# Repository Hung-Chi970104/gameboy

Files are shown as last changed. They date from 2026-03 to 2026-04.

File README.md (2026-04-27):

# Pico Gameboy
I came across with this DIY Gameboy video made of Raspberry Pi Pico and inspired me to build my own version. The fact that RP2040 has dual-core ARM Cortex-M0+ processor makes it capable of running some light emulators. So I’ll build a little handheld game console using RP2040 that can run gameboy!
### Kirby's Dream Land 2 (My favorite)
https://github.com/user-attachments/assets/909a369a-9677-4903-9628-0e65bedbe7ed

### Tetris (my unemployed friend LMAO)
https://github.com/user-attachments/assets/1b85eab4-04bd-4f8f-a2d0-78ee750a4273

# Features
- Full-on Gameboy experience: Actually runs the classics smoothly without freaking out.
- Insanely portable: Squeezed everything into a super compact custom PCB so you can just chuck it in your pocket.
- 100% Custom Hardware: Fully designed, routed, and reflowed by yours truly (my eyes are still bleeding from staring at KiCad traces bruh).

# Components
- RP2040
- 12MHz Crystal (ABM8-272-T3)
- 8MB Flash Storage (W25Q64JVXGIQ)
- Buck-Boost Switching Regulator (RT6150B)
- USB-C (TYPE-C-31-M-12)

# PCB Designs
- 2 layers
- Single-sided component placement
- 2.6mm board thickness
- HASL (with lead) surface finish
- 1oz outer copper weight

## PCB Schematic
schemtatic

## PCB Layouts
pcb_front
pcb_back
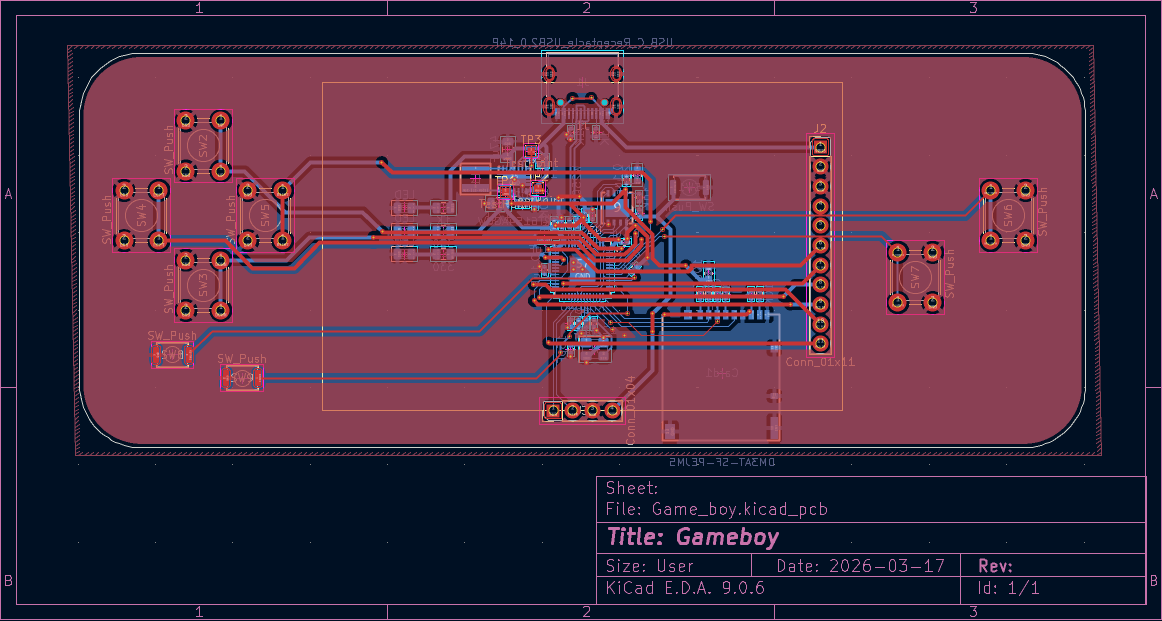
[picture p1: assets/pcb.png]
pcb_design


## 3D Model
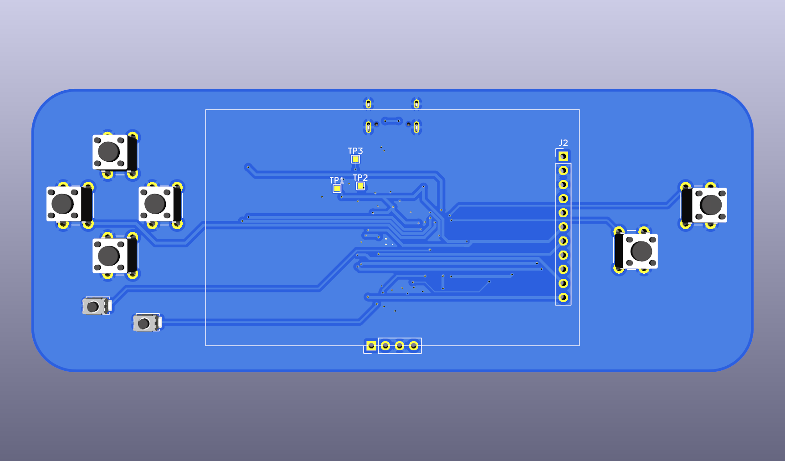
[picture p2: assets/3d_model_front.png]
3d_model_front

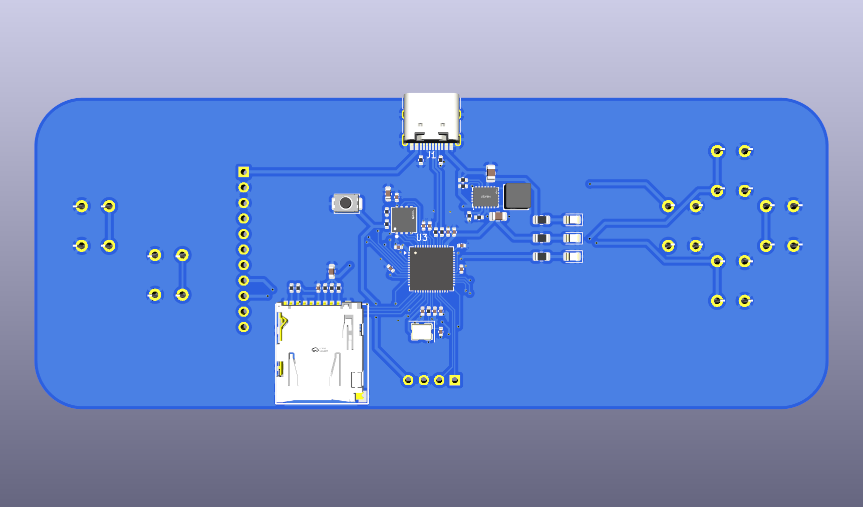
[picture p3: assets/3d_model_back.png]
3d_model_back


# How to order
- Download the zip file
- Upload the zip file to JLCPCB
- Select PCBA and continue
- Upload BOM.csv and position.csv
- Select the parts and submit payment

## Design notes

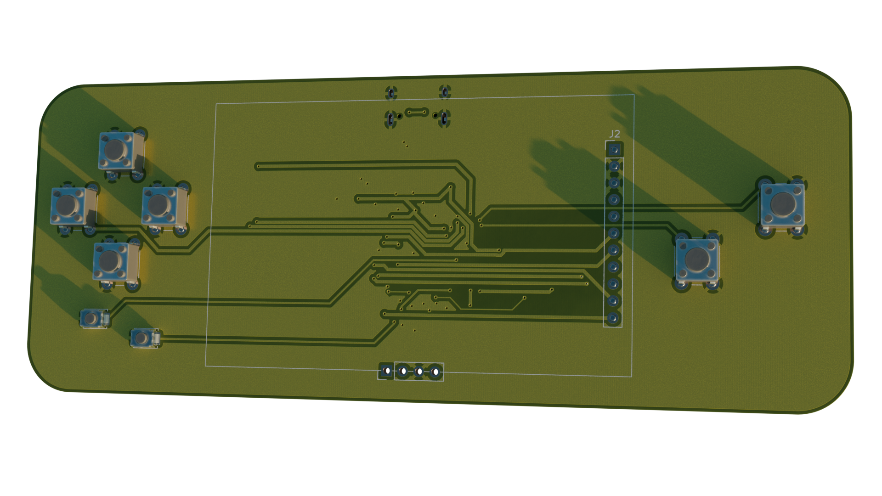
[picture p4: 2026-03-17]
assets/gameboy_front.png

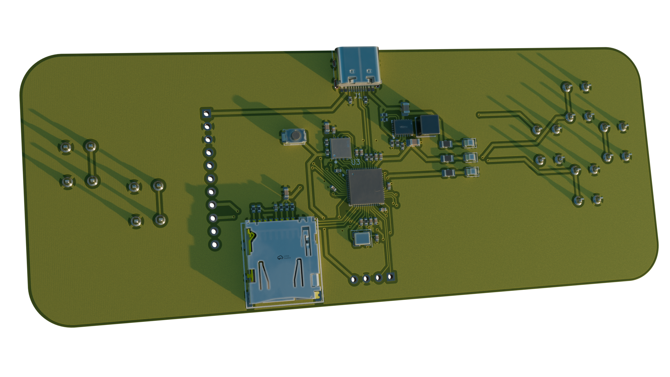
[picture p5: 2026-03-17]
assets/gameboy.png

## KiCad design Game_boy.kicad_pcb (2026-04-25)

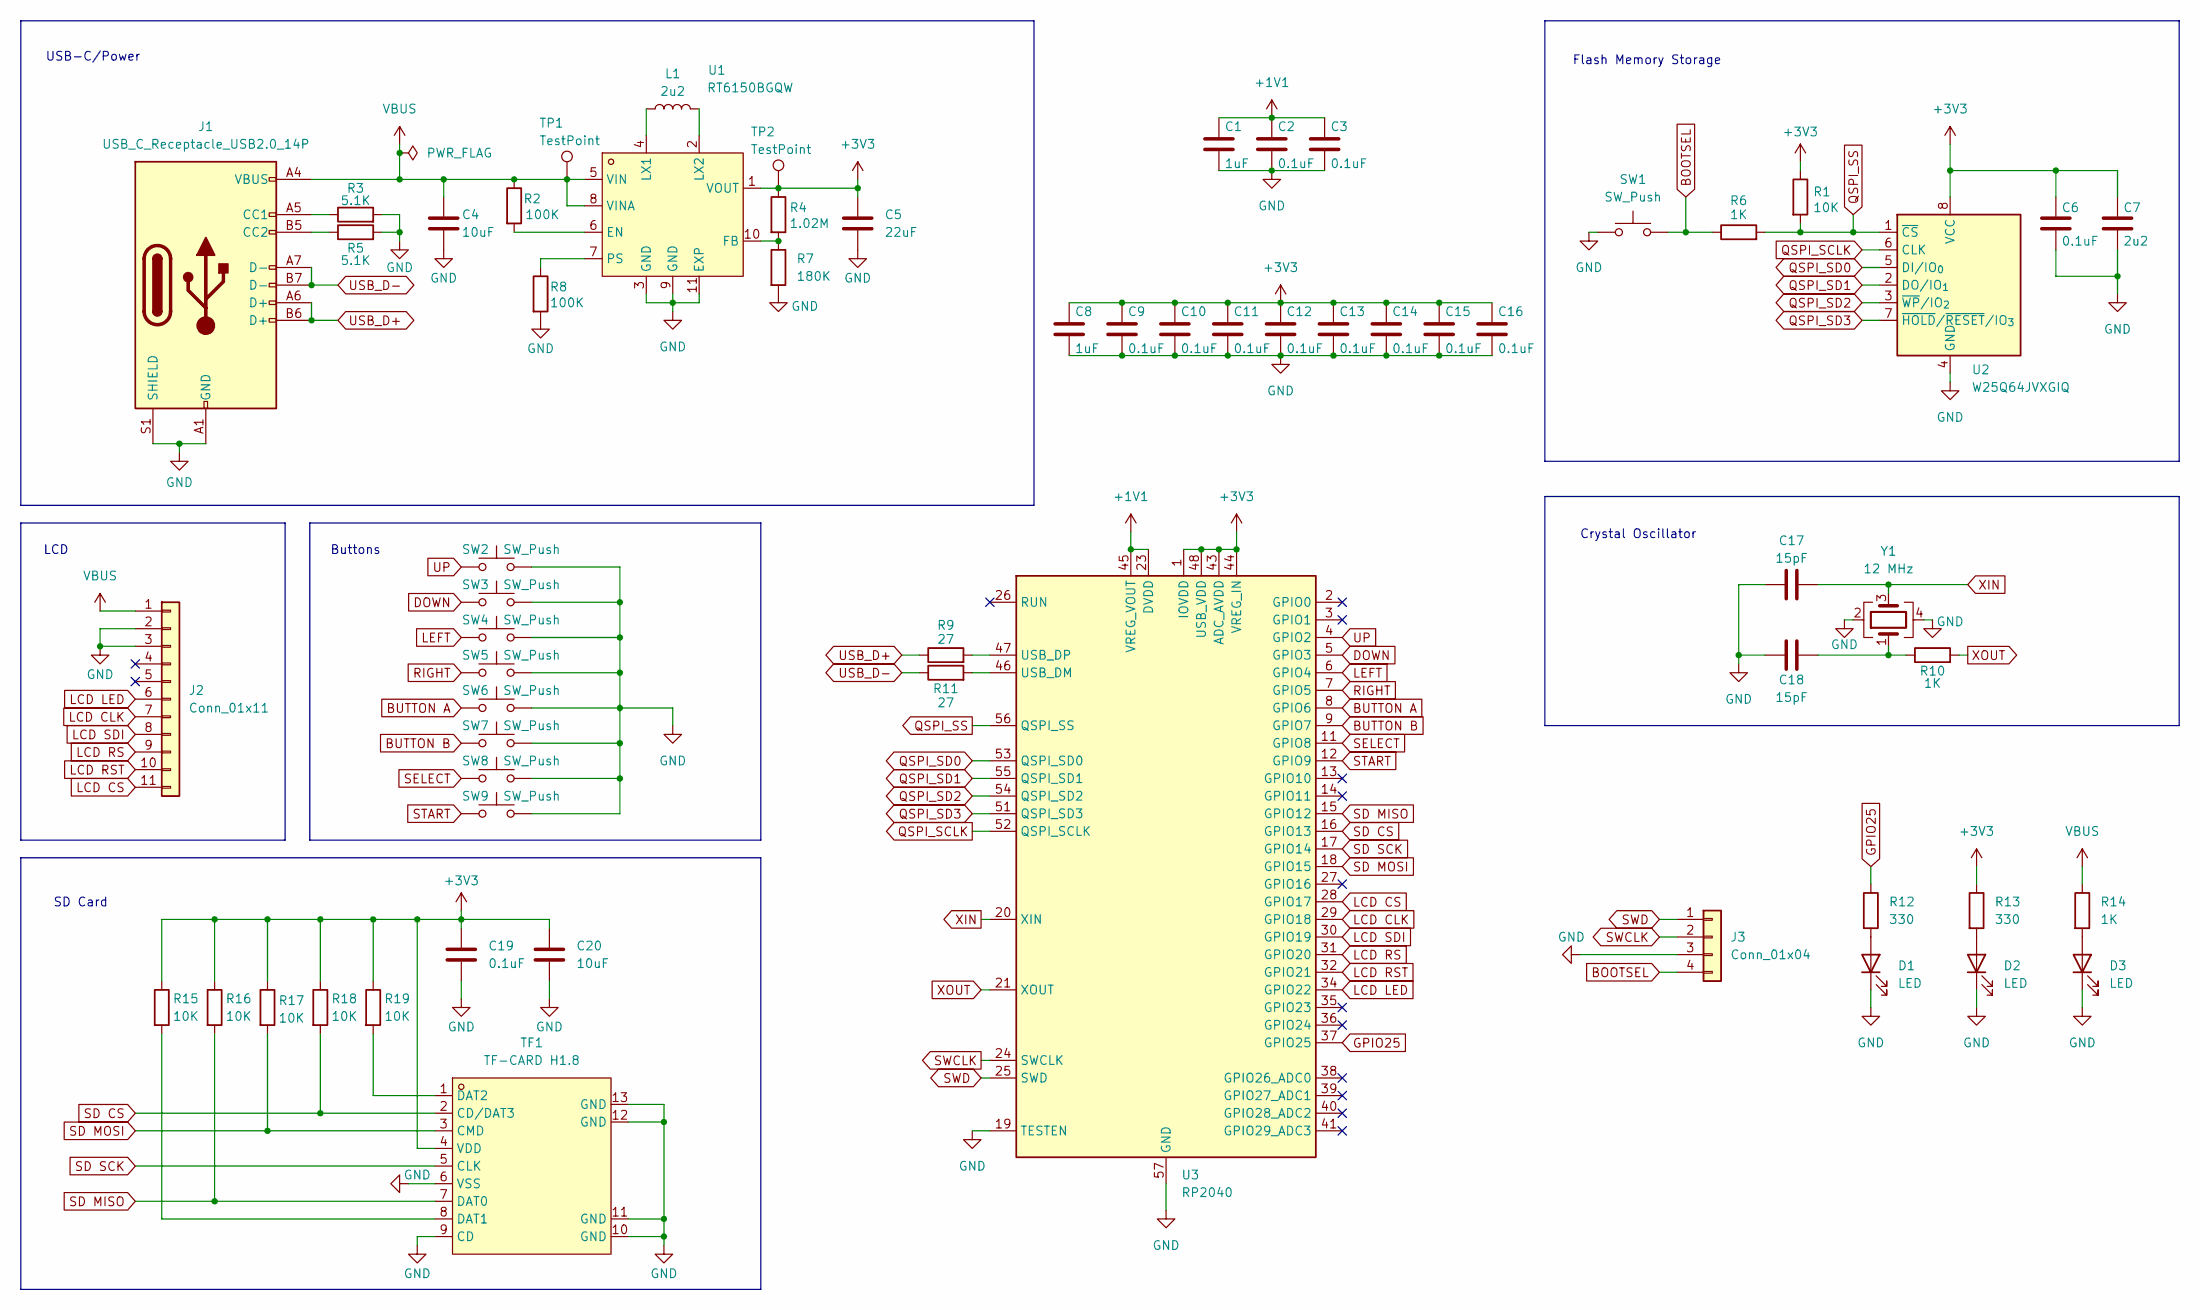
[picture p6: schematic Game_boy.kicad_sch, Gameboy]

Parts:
C1, C8: 1uF; C_0402_1005Metric
C2, C3, C6, C9, C10, C11, C12, C13, C14, C15, C16, C19: 0.1uF; C_0402_1005Metric
C4: 10uF; C_1206_3216Metric
C5: 22uF; C_1206_3216Metric
C7: 2u2; C_0603_1608Metric
C17, C18: 15pF; C_0402_1005Metric
C20: 10uF; C_0603_1608Metric
D1, D2, D3: LED; LED_0805_2012Metric
J1: USB_C_Receptacle_USB2.0_14P; USB_C_Receptacle_HRO_TYPE-C-31-M-12
J2: Conn_01x11; PinHeader_1x11_P2.54mm_Vertical
J3: Conn_01x04; PinHeader_1x04_P2.54mm_Vertical
L1: 2u2; IND-SMD_L4.0-W4.0_XAL4030-332MEC
R1, R15, R16, R17, R18, R19: 10K; R_0402_1005Metric
R2, R8: 100K; R_0402_1005Metric
R3, R5: 5.1K; R_0402_1005Metric
R4: 1.02M; R_0402_1005Metric
R6, R10: 1K; R_0402_1005Metric
R7: 180K; R_0402_1005Metric
R9, R11: 27; R_0402_1005Metric
R12, R13: 330; R_0805_2012Metric
R14: 1K; R_0805_2012Metric
SW1, SW8, SW9: SW_Push; SW_Push_SPST_NO_Alps_SKRK
SW2, SW3, SW4, SW5, SW6, SW7: SW_Push; SW_PUSH_6mm
TF1: TF-CARD H1.8; TF-SMD_TF-CARD-H1.8; LCSC Part C7529389
TP1, TP2: TestPoint; TestPoint_Pad_1.0x1.0mm
U1: RT6150BGQW; WSON-10_L2.5-W2.5-P0.50-BL-EP; LCSC Part C147972
U2: W25Q64JVXGIQ; XSON-8_L4.0-W4.0-P0.80-TL-EP
U3: RP2040; QFN-56-1EP_7x7mm_P0.4mm_EP3.2x3.2mm
Y1: 12 MHz; Crystal_SMD_3225-4Pin_3.2x2.5mm

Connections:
+1V1: C1.1, C2.1, C3.1, U3.23 (DVDD), U3.45 (VREG_VOUT), U3.50 (DVDD)
+3V3: C5.1, C6.1, C7.1, C8.1, C9.1, C10.1, C11.1, C12.1, C13.1, C14.1, C15.1, C16.1, C19.1, C20.1, R1.1, R4.1, R13.1, R15.1, R16.1, R17.1, R18.1, R19.1, TF1.4 (VDD), TP2.1, U1.1 (VOUT), U2.8 (VCC), U3.1 (IOVDD), U3.10 (IOVDD), U3.22 (IOVDD), U3.33 (IOVDD), U3.42 (IOVDD), U3.43 (ADC_AVDD), U3.44 (VREG_IN), U3.48 (USB_VDD), U3.49 (IOVDD)
BOOTSEL: J3.4, R6.1, SW1.2
BUTTON A: SW6.1, U3.8 (GPIO6)
BUTTON B: SW7.1, U3.9 (GPIO7)
DOWN: SW3.1, U3.5 (GPIO3)
GND: C1.2, C2.2, C3.2, C4.2, C5.2, C6.2, C7.2, C8.2, C9.2, C10.2, C11.2, C12.2, C13.2, C14.2, C15.2, C16.2, C17.1, C18.1, C19.2, C20.2, D1.1 (K), D2.1 (K), D3.1 (K), J1.A1 (GND), J1.A12 (GND), J1.B1 (GND), J1.B12 (GND), J1.S1 (SHIELD), J2.2, J2.3, J3.3, R3.2, R5.2, R7.2, R8.2, SW1.1, SW2.2, SW3.2, SW4.2, SW5.2, SW6.2, SW7.2, SW8.2, SW9.2, TF1.6 (VSS), TF1.9 (CD), TF1.10 (GND), TF1.11 (GND), TF1.12 (GND), TF1.13 (GND), U1.3 (GND), U1.9 (GND), U1.11 (EXP), U2.4 (GND), U3.19 (TESTEN), U3.57 (GND), Y1.2, Y1.4
GPIO25: R12.1, U3.37 (GPIO25)
LCD CLK: J2.7, U3.29 (GPIO18)
LCD CS: J2.11, U3.28 (GPIO17)
LCD LED: J2.6, U3.34 (GPIO22)
LCD RS: J2.9, U3.31 (GPIO20)
LCD RST: J2.10, U3.32 (GPIO21)
LCD SDI: J2.8, U3.30 (GPIO19)
LEFT: SW4.1, U3.6 (GPIO4)
unnamed: C18.2, R10.1, Y1.1
unnamed: D1.2 (A), R12.2
unnamed: D2.2 (A), R13.2
unnamed: D3.2 (A), R14.2
unnamed: J1.A5 (CC1), R3.1
unnamed: J1.B5 (CC2), R5.1
unnamed: R15.2, TF1.8 (DAT1)
unnamed: R19.2, TF1.1 (DAT2)
unnamed: R2.2, U1.6 (EN)
unnamed: R4.2, R7.1, U1.10 (FB)
unnamed: L1.1, U1.4 (LX1)
unnamed: L1.2, U1.2 (LX2)
unnamed: R8.1, U1.7 (PS)
unnamed: R11.2, U3.46 (USB_DM)
unnamed: R9.2, U3.47 (USB_DP)
QSPI_SCLK: U2.6 (CLK), U3.52 (QSPI_SCLK)
QSPI_SD0: U2.5 (DI/IO_{0}), U3.53 (QSPI_SD0)
QSPI_SD1: U2.2 (DO/IO_{1}), U3.55 (QSPI_SD1)
QSPI_SD2: U2.3 (~WP/IO_{2}), U3.54 (QSPI_SD2)
QSPI_SD3: U2.7 (~HOLD/~RESET/IO_{3}), U3.51 (QSPI_SD3)
QSPI_SS: R1.2, R6.2, U2.1 (~CS), U3.56 (QSPI_SS)
RIGHT: SW5.1, U3.7 (GPIO5)
SD CS: R18.2, TF1.2 (CD/DAT3), U3.16 (GPIO13)
SD MISO: R16.2, TF1.7 (DAT0), U3.15 (GPIO12)
SD MOSI: R17.2, TF1.3 (CMD), U3.18 (GPIO15)
SD SCK: TF1.5 (CLK), U3.17 (GPIO14)
SELECT: SW8.1, U3.11 (GPIO8)
START: SW9.1, U3.12 (GPIO9)
SWCLK: J3.2, U3.24 (SWCLK)
SWD: J3.1, U3.25 (SWD)
UP: SW2.1, U3.4 (GPIO2)
USB_D+: J1.A6 (D+), J1.B6 (D+), R9.1
USB_D-: J1.A7 (D-), J1.B7 (D-), R11.1
VBUS: C4.1, J1.A4 (VBUS), J1.A9 (VBUS), J1.B4 (VBUS), J1.B9 (VBUS), J2.1, R2.1, R14.1, TP1.1, U1.5 (VIN), U1.8 (VINA)
XIN: C17.2, U3.20 (XIN), Y1.3
XOUT: R10.2, U3.21 (XOUT)

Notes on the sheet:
LCD
SD Card
Flash Memory Storage
USB-C/Power
Crystal Oscillator
Buttons

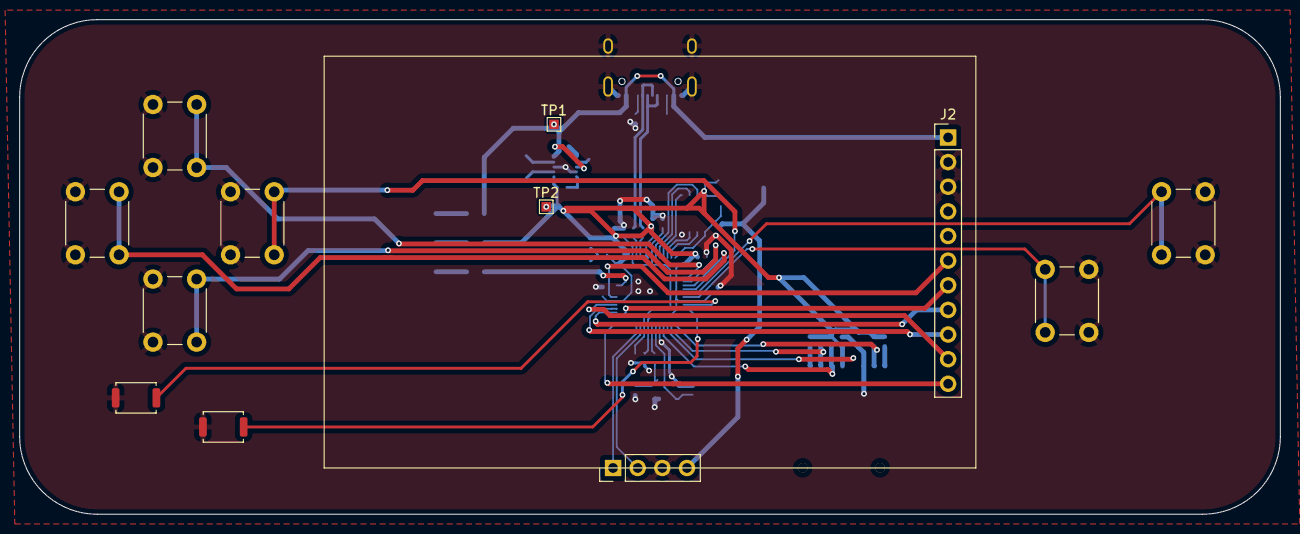
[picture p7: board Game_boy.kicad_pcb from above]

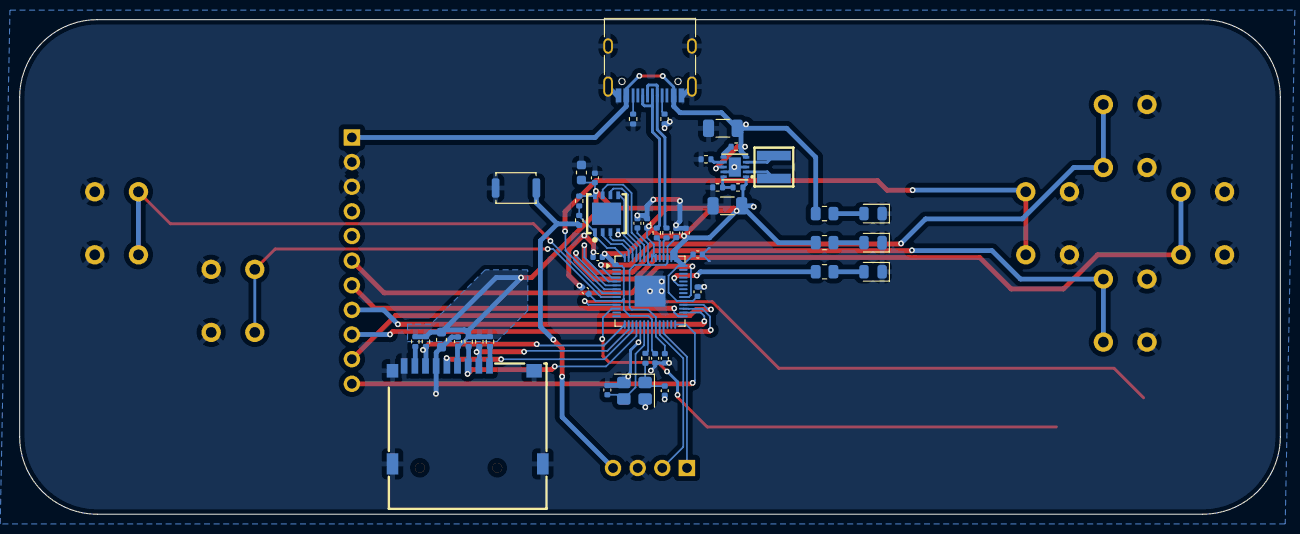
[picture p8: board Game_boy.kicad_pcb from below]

Board: 2 copper layers, 130.0 x 51.0 mm, 60 parts (48 on the bottom side), 51 nets.
